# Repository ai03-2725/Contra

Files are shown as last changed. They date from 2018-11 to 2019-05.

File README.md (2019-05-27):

# Contra
Extremely low cost ortholinear keyboard

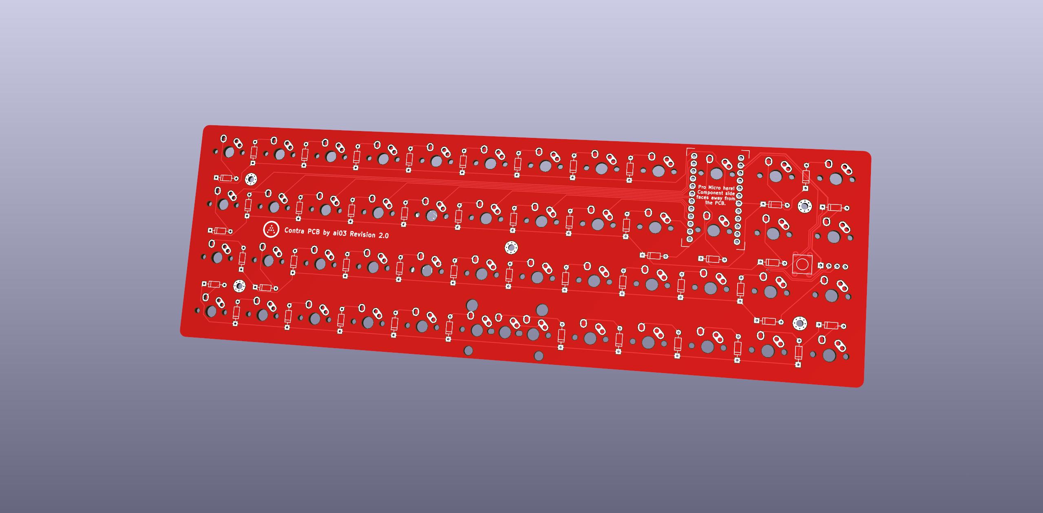
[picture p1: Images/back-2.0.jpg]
Render


The bare minimum for a functional keyboard.

#### In light of recent claims that I am 100% liable for any of my open source PCBs, I am adding this disclaimer.
#### I provide these PCBs as a reference for designing keyboard PCBs. Using them within your projects will require a will to do research of one's own and to learn the workings of them, potentially fixing issues if they exist.
# I provide these PCBs without liability and without any guarantees regarding functionality, as expressed in the MIT license under which all of these PCBs are licensed.

### Features
- 2U or split space.
- All through-hole parts. 48x diodes, 1x Pro Micro.
- Assembled by M2 standoffs and screws.
- Programmable via firmware of choice, such as TMK.
- Nothing fancy. A very nice way to try out some switches, enjoy some DIY, or to test out ortho keyboards.

### Parts list
- 48x 1N4148 diodes or similar, THT
- 1x Pro Micro
- 48x Switches
- Optional 1x 2U stabilizer, PCB mount
- One PCB, one plate, and one bottom plate
- 5 M2 8mm standoffs
- 10 M2 screws

### Files for production
- Main PCB: Check the [latest releases](https://github.com/ai03-2725/Contra/releases), or grab the latest gerber [here](https://github.com/ai03-2725/Contra/blob/master/Gerbers/Gerbers.zip).
- Case files: Check the case repo [here](https://github.com/ai03-2725/ContraPlates).

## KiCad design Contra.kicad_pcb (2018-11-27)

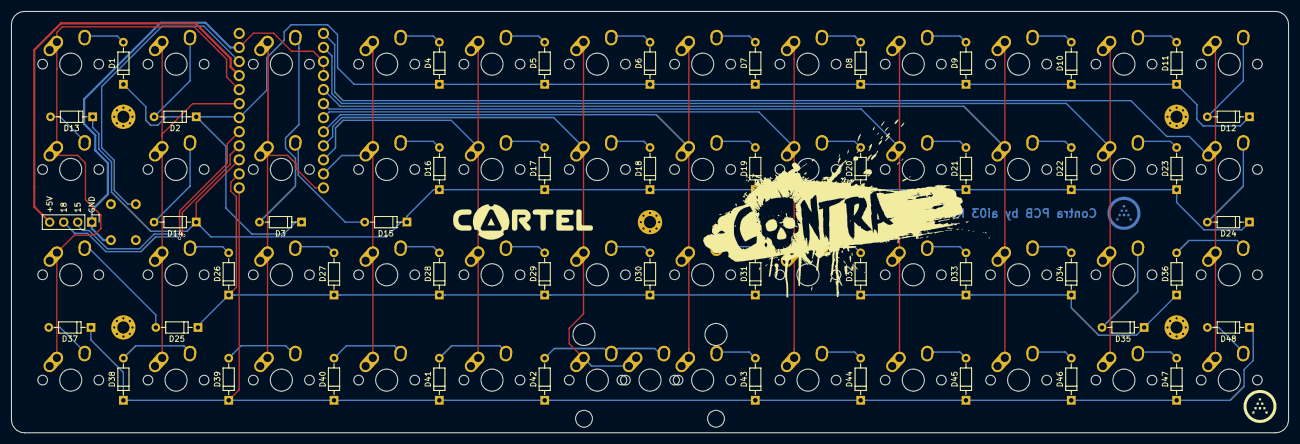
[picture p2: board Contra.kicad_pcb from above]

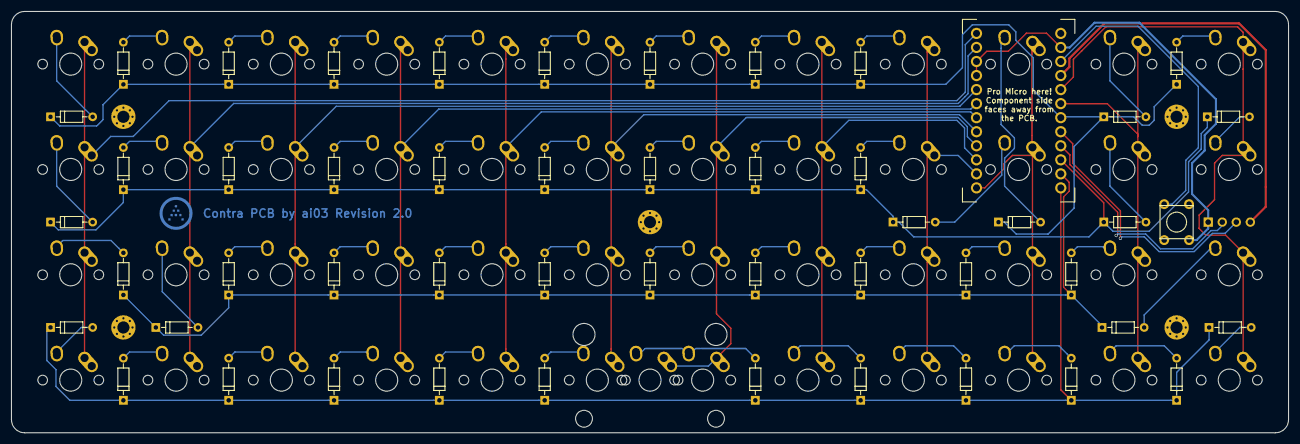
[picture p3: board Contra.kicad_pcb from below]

Board: 2 copper layers, 231.0 x 76.2 mm, 100 parts (2 on the bottom side), 69 nets.

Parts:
D1, D2, D3, D4, D5, D6, D7, D8, D9, D10, D11, D12, D13, D14, D15, D16, D17, D18, D19, D20, D21, D22, D23, D24, D25, D26, D27, D28, D29, D30, D31, D32, D33, D34, D35, D36, D37, D38, D39, D40, D41, D42, D43, D44, D45, D46, D47, D48: 1N4148; D_DO-35_SOD27_P7.62mm_Horizontal-DoubleSided
J1: Conn_01x04; Pin_Header_Straight_1x04_Pitch2.54mm
MX1, MX2, MX3, MX4, MX5, MX6, MX7, MX8, MX9, MX10, MX11, MX12, MX13, MX14, MX15, MX16, MX17, MX18, MX19, MX20, MX21, MX22, MX23, MX24, MX25, MX26, MX27, MX28, MX29, MX30, MX31, MX32, MX33, MX34, MX35, MX36, MX37, MX38, MX39, MX40, MX41, MX42, MX43, MX44, MX45, MX46, MX47, MX48: MX-1U; MX-1U-NoLED
MX49: MX-2U; MX-2U-ReversedStabilizers-NoLED
SW1: SW_PUSH; PushButton_6x6mm_TH_Pretty
U1: ProMicro; pro_micro

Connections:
+5V: J1.4, U1.21
COL0: MX1.1, MX13.1, MX25.1, MX37.1, U1.20
COL1: MX2.1, MX14.1, MX26.1, MX38.1, U1.19
COL2: MX3.1, MX15.1, MX27.1, MX39.1, U1.12
COL3: MX4.1, MX16.1, MX28.1, MX40.1, U1.11
COL4: MX5.1, MX17.1, MX29.1, MX41.1, U1.10
COL5: MX6.1, MX18.1, MX30.1, MX42.1, MX49.1, U1.9
COL6: MX7.1, MX19.1, MX31.1, MX43.1, U1.8
COL7: MX8.1, MX20.1, MX32.1, MX44.1, U1.7
COL8: MX9.1, MX21.1, MX33.1, MX45.1, U1.6
COL9: MX10.1, MX22.1, MX34.1, MX46.1, U1.5
COL10: MX11.1, MX23.1, MX35.1, MX47.1, U1.2
COL11: MX12.1, MX24.1, MX36.1, MX48.1, U1.1
GND: J1.1, SW1.2, U1.3, U1.4, U1.23
unnamed: D1.2, MX1.2
unnamed: D2.2, MX2.2
unnamed: D3.2, MX3.2
unnamed: D4.2, MX4.2
unnamed: D5.2, MX5.2
unnamed: D6.2, MX6.2
unnamed: D7.2, MX7.2
unnamed: D8.2, MX8.2
unnamed: D9.2, MX9.2
unnamed: D10.2, MX10.2
unnamed: D11.2, MX11.2
unnamed: D12.2, MX12.2
unnamed: D13.2, MX13.2
unnamed: D14.2, MX14.2
unnamed: D15.2, MX15.2
unnamed: D16.2, MX16.2
unnamed: D17.2, MX17.2
unnamed: D18.2, MX18.2
unnamed: D19.2, MX19.2
unnamed: D20.2, MX20.2
unnamed: D21.2, MX21.2
unnamed: D22.2, MX22.2
unnamed: D23.2, MX23.2
unnamed: D24.2, MX24.2
unnamed: D25.2, MX25.2
unnamed: D26.2, MX26.2
unnamed: D27.2, MX27.2
unnamed: D28.2, MX28.2
unnamed: D29.2, MX29.2
unnamed: D30.2, MX30.2
unnamed: D31.2, MX31.2
unnamed: D32.2, MX32.2
unnamed: D33.2, MX33.2
unnamed: D34.2, MX34.2
unnamed: D35.2, MX35.2
unnamed: D36.2, MX36.2
unnamed: D37.2, MX37.2
unnamed: D38.2, MX38.2
unnamed: D39.2, MX39.2
unnamed: D40.2, MX40.2
unnamed: D41.2, MX41.2
unnamed: D42.2, MX42.2, MX49.2
unnamed: D43.2, MX43.2
unnamed: D44.2, MX44.2
unnamed: D45.2, MX45.2
unnamed: D46.2, MX46.2
unnamed: D47.2, MX47.2
unnamed: D48.2, MX48.2
unnamed: SW1.1, U1.22
PIN15: J1.2, U1.16
PIN18: J1.3, U1.17
ROW0: D1.1, D2.1, D3.1, D4.1, D5.1, D6.1, D7.1, D8.1, D9.1, D10.1, D11.1, D12.1, U1.18
ROW1: D13.1, D14.1, D15.1, D16.1, D17.1, D18.1, D19.1, D20.1, D21.1, D22.1, D23.1, D24.1, U1.15
ROW2: D25.1, D26.1, D27.1, D28.1, D29.1, D30.1, D31.1, D32.1, D33.1, D34.1, D35.1, D36.1, U1.14
ROW3: D37.1, D38.1, D39.1, D40.1, D41.1, D42.1, D43.1, D44.1, D45.1, D46.1, D47.1, D48.1, U1.13

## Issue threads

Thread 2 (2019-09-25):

Cases and or plates

nschurmann, 2019-09-25:
Hello! i'm trying to find mounting plate or cases for this pcb, i've got 5 but i can't find any on internet. I don't have a 3d printer so i cannot print the suggested case. Any recommendation on tihs?

kuwatay, 2021-01-13:
https://www.thingiverse.com/thing:4402730

genaro14, 2022-08-09:
https://www.thingiverse.com/thing:5162848

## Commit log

2017-12-06 Begin schematic
    [Danck.kicad_pcb, Danck.sch]
2017-12-06 Finish schematic
    Well... that was fast
    [Danck.sch]
2017-12-06 Begin building pcb
    [Danck.kicad_pcb]
2017-12-06 row 3 is in
    [Danck.kicad_pcb]
2017-12-06 Finish grid
    [Danck.kicad_pcb]
2017-12-07 Finish the dank memes
    [Danck.kicad_pcb, Danck.sch]
2017-12-07 Generate gerbers
    [Danck-B.Cu.gbl, Danck-B.Mask.gbs, Danck-B.SilkS.gbo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]
2017-12-07 Plot dimensions for drilling reset hole in bottom
    [Danck-B.Cu.dxf, Danck-B.Mask.dxf, Danck-B.SilkS.dxf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]
2017-12-07 Fix DRC error, update gerbers
    [Danck.kicad_pcb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]
2017-12-08 Unroute for moving pmicro
    [Danck.kicad_pcb]
2017-12-08 Finish reroute
    [Danck.kicad_pcb]
2017-12-08 Make gnd plane flow better
    [Danck.kicad_pcb]
2017-12-08 Update gerbers
    [Danck-B.Cu.gbl, Danck-B.Mask.gbs, Danck-B.SilkS.gbo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]
2017-12-09 Update some memes
    [Danck.kicad_pcb]
2017-12-09 New gerbs
    [Danck-B.Cu.gbl, Danck-B.Mask.gbs, Danck-B.SilkS.gbo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]
2017-12-14 breakout pins
    [Danck.kicad_pcb, Danck.sch]
2017-12-14 Update gerber
    [Danck-B.Cu.gbl, Danck-B.Mask.gbs, Danck-B.SilkS.gbo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]
2017-12-20 Add memes and update gerber
    [Danck.kicad_pcb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]
2017-12-22 Update footprints for silk
    [Danck.kicad_pcb]
2017-12-22 Reposition memes, add you won't download...
    [Danck.kicad_pcb]
2017-12-22 New gerbers
    [Danck-B.Cu.gbl, Danck-B.Mask.gbs, Danck-B.SilkS.gbo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]
2018-01-14 Remove some images
    [Danck.kicad_pcb]
2018-01-14 Revert "Remove some images"
    This reverts commit 0baf5fd5442c26d070a6e67100257904d2560f5a.
    [Danck.kicad_pcb]
2018-01-14 Improve routing, add broken image
    [Danck.kicad_pcb]
2018-01-14 Update some routing
    [Danck.kicad_pcb]
2018-01-15 Remove some artworkr
    [Danck.kicad_pcb]
2018-01-16 Add de wey
    [Danck.kicad_pcb]
2018-01-16 Plot new width dimensions
    [Danck.kicad_pcb]
2018-01-16 Extend board on each side
    [Danck.kicad_pcb]
2018-01-16 Update revisions, update gerbers
    [Danck.kicad_pcb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]
2018-02-09 Generate RS-274-X gerbers
    [Danck-B.Cu.gbl, Danck-B.Mask.gbs, Danck-B.SilkS.gbo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]
2018-03-17 Rename project files
    [Contra-B.Cu.gbl, Contra-B.Mask.gbs, Contra-B.SilkS.gbo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]
2018-04-03 No silk gerber created
2018-04-03 Update footprints to latest
2018-04-03 Fix issues present in R1
    - Diode silkscreen conflict fixed
    - Fix pinout on RGB breakout
    - Update footprints to Rev2
    [Contra.kicad_pcb]
2018-04-03 Generate new gerbers
    [Contra-B.Cu.gbl, Contra-B.Mask.gbs, Contra-B.SilkS.gbo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]
2018-11-27 Unroute, prepare for reroute
    [Contra.kicad_pcb]
2018-11-27 Revert "Unroute, prepare for reroute"
    This reverts commit 2692a349e5744fa5fd6682816f15a667edd49ab0.
    [Contra.kicad_pcb]
2018-11-27 Opt to reroute instead of rebuild from scratch
    [Contra.kicad_pcb]
2018-11-27 Repair the mess of questionable routing decisions
    [Contra.kicad_pcb]
2018-11-27 Convert to KiCad 5
    [Contra-2018-11-27-00-13-32.sch, Contra.kicad_pcb]
2018-11-27 Update locallib
    [Contra.sch]
2018-11-27 Make diodes double sided
    [Contra.sch]
